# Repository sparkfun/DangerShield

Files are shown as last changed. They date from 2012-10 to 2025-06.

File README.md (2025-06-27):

Danger Shield
=============

[Danger Shield  
*Danger Shield (DEV-10570)*](https://www.sparkfun.com/products/10570)

This is the layout and example code for the Danger Shield product by SparkFun Electronics. It demonstrates each feature of the shield. Move one of the sliders to get a different sound out of the buzzer. Move another slider to change the digit being displayed on the seven segment display. Move the last slider to change the brightness of one of the two status LEDs. Press one of the large buttons to toggle on/off the status LED. Cover the light sensor to 'scare' the unit.

The idea of a Danger Shield was originally created by Zach Hoeken ([http://www.zachhoeken.com/](http://www.zachhoeken.com/))

Repository Contents
-------------------
* **/Firmware** - Example Arduino Sketch
* **/Hardware** - All Eagle design files (.brd, .sch)

Product History
---------------

[DEV-09597](https://www.sparkfun.com/products/9597) - *retired*  
The original version of the Danger Shield which has since been retired.

[DEV-10115](https://www.sparkfun.com/products/10115) - *retired*  
Second version which introduced a knock sensor and a new temperature sensor. Has since been retired.

**[DEV-10570](https://www.sparkfun.com/products/10570) - current version**  
This newest version introduces a capacitive touch sensor. All code in this repository will work best with this version.

License Information
-------------------

The hardware is released under [Creative Commons Share-alike 3.0](http://creativecommons.org/licenses/by-sa/3.0/).  
The code is public domain but you buy me a beer if you use this and we meet someday ([Beerware license](http://en.wikipedia.org/wiki/Beerware)).

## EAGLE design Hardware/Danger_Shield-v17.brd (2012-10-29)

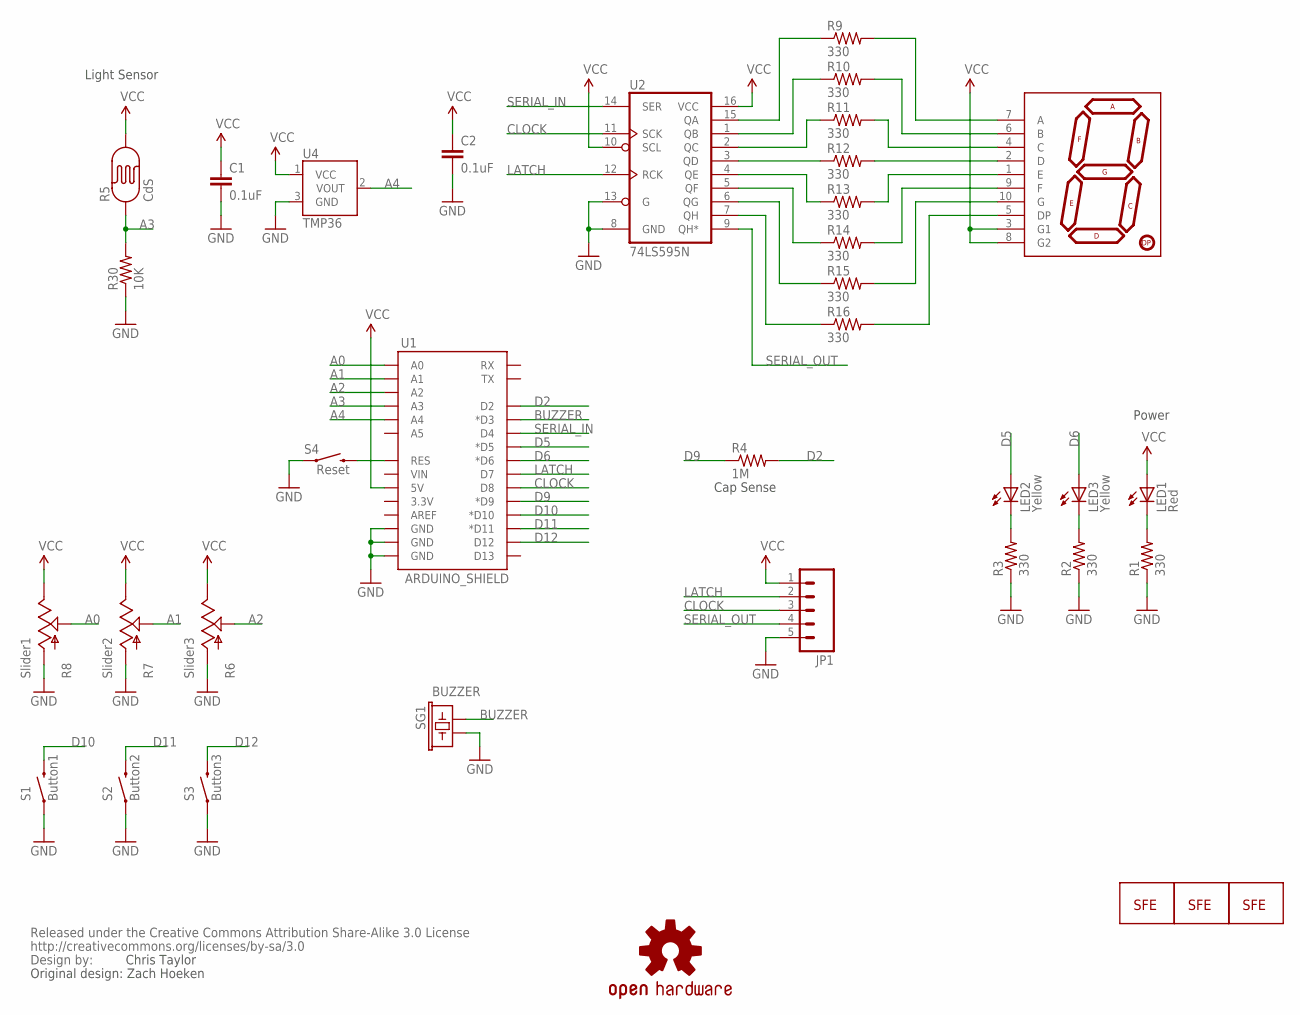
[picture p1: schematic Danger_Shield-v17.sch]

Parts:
C1, C2: 0.1uF; CAP-PTH-SMALL2
JP1: M05PTH; 1X05
JP2, JP3: LOGO-SFENEW; SFE-NEW-WEBLOGO
JP5: LOGO-SFESK; SFE-LOGO-FLAME
LED1: Red; LED5MM
LED2, LED3: Yellow; LED5MM
R1, R2, R3, R9, R10, R11, R12, R13, R14, R15, R16: 330; AXIAL-0.3
R4: 1M; AXIAL-0.3
R5: CdS; PHOTOCELL
R6: Slider3; SLIDER
R7: Slider2; SLIDER
R8: Slider1; SLIDER
R30: 10K; AXIAL-0.3
S1: Button1; TACTILE-PTH-12MM
S2: Button2; TACTILE-PTH-12MM
S3: Button3; TACTILE-PTH-12MM
S4: Reset; TACTILE-PTH
SG1: BUZZER; BUZZER-12MM
U1: ARDUINO_SHIELD; DUEMILANOVE_VIAS
U2: 74LS595N; DIL16
U4: TMP36; TO-92
U6: 7-SEGMENT-DISPLAY-1"-RED; 7-SEGMENT-1"PTH
U$1: CREATIVE_COMMONS
U$2: OSHW-LOGOM; OSHW-LOGO-M

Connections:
A0: R8.2A (S), U1.A0
A1: R7.2A (S), U1.A1
A2: R6.2A (S), U1.A2
A3: R5.1, R30.P$2 (2), U1.A3
A4: U1.A4, U4.2 (VOUT)
BUZZER: SG1.+ (1), U1.D3 (*D3)
CLOCK: JP1.3, U1.D8, U2.11 (SCK)
D2: R4.P$2 (2), U1.D2
D5: LED2.A, U1.D5 (*D5)
D6: LED3.A, U1.D6 (*D6)
D9: R4.P$1 (1), U1.D9 (*D9)
D10: S1.3 (2), U1.D10 (*D10)
D11: S2.3 (2), U1.D11 (*D11)
D12: S3.3 (2), U1.D12
GND: C1.2, C2.2, JP1.5, R1.P$1 (1), R2.P$1 (1), R3.P$1 (1), R6.3 (A), R7.3 (A), R8.3 (A), R30.P$1 (1), S1.1, S2.1, S3.1, S4.1, SG1.- (2), U1.GND@0 (GND), U1.GND@1 (GND), U1.GND@2 (GND), U2.8 (GND), U2.13 (G), U4.3 (GND)
LATCH: JP1.2, U1.D7, U2.12 (RCK)
unnamed: S4.3 (2), U1.RES
unnamed: R9.P$1 (1), U2.15 (QA)
unnamed: LED1.K (C), R1.P$2 (2)
unnamed: R10.P$1 (1), U2.1 (QB)
unnamed: R11.P$1 (1), U2.2 (QC)
unnamed: R12.P$1 (1), U2.3 (QD)
unnamed: R13.P$1 (1), U2.4 (QE)
unnamed: R14.P$1 (1), U2.5 (QF)
unnamed: R15.P$1 (1), U2.6 (QG)
unnamed: R16.P$1 (1), U2.7 (QH)
unnamed: R9.P$2 (2), U6.7 (A)
unnamed: R10.P$2 (2), U6.6 (B)
unnamed: R11.P$2 (2), U6.4 (C)
unnamed: R12.P$2 (2), U6.2 (D)
unnamed: R13.P$2 (2), U6.1 (E)
unnamed: R14.P$2 (2), U6.9 (F)
unnamed: R15.P$2 (2), U6.10 (G)
unnamed: R16.P$2 (2), U6.5 (DP)
unnamed: LED3.K (C), R2.P$2 (2)
unnamed: LED2.K (C), R3.P$2 (2)
SERIAL_IN: U1.D4, U2.14 (SER)
SERIAL_OUT: JP1.4, U2.9 (QH*)
VCC: C1.1, C2.1, JP1.1, LED1.A, R5.2, R6.1 (E), R7.1 (E), R8.1 (E), U1.5V, U2.10 (SCL), U2.16 (VCC), U4.1 (VCC), U6.3 (G1), U6.8 (G2)

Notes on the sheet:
Power
Light Sensor
Cap Sense
Chris Taylor
Original design: Zach Hoeken

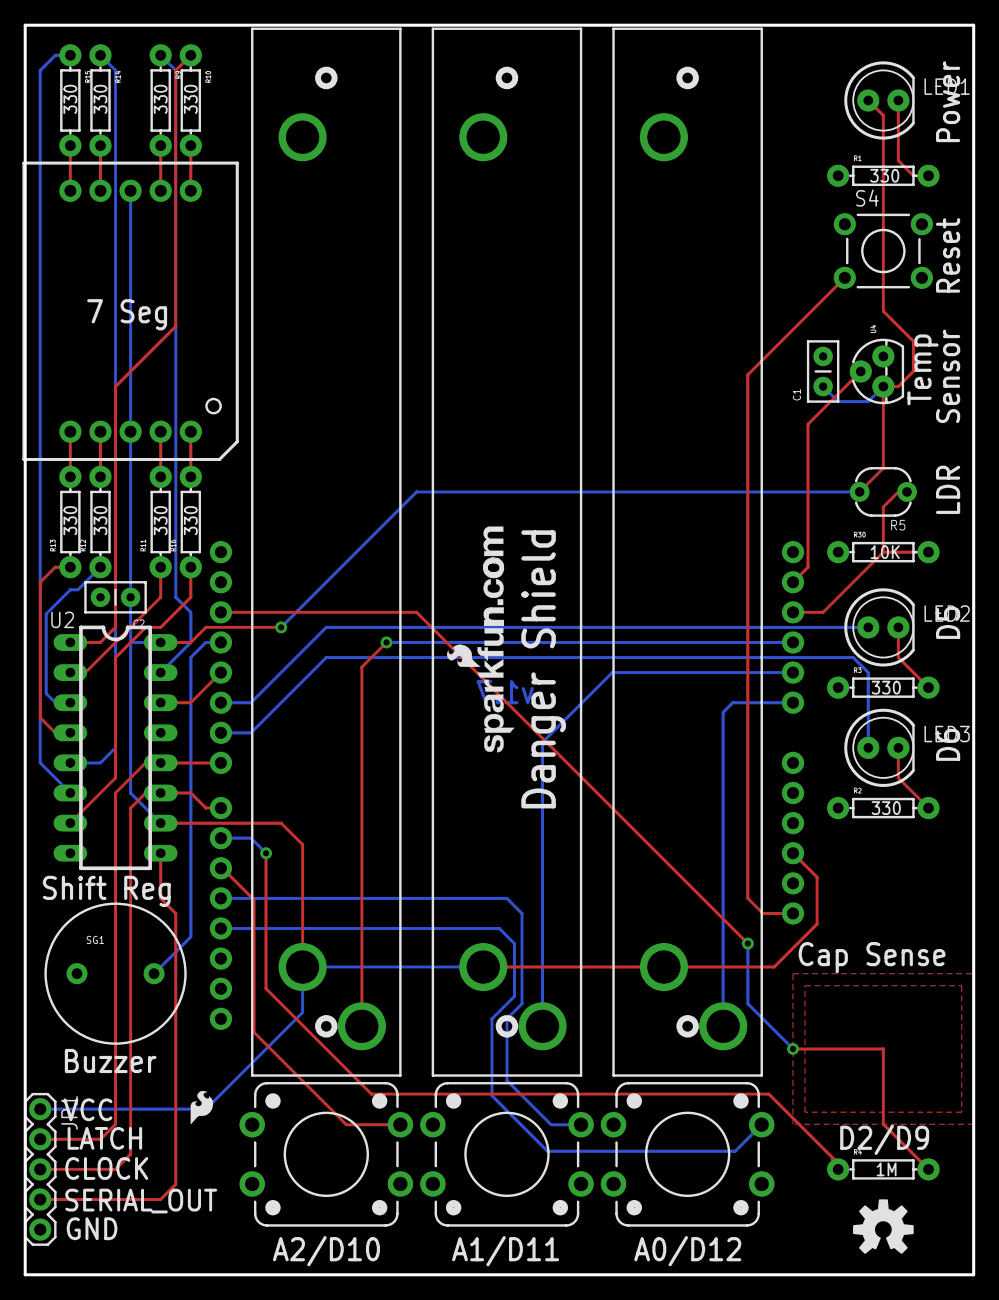
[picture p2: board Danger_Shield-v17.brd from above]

Board: 2 copper layers, 80.0 x 105.4 mm, 37 parts (1 on the bottom side), 39 nets.

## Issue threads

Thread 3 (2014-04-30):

map() scales the slider values from 0 to 1020?

bhuang10000, 2014-04-30:
In the sample code, the slider values are scaled from a range of 0 to 1020 not 0 to 1023? Is there a reason for this?

Marsfan, 2015-01-14:
I just forked and fixed this.
Pull request submitted.

ToniCorinne, 2016-03-09:
Fixed with merging pull request #4

Closed 2016-03-09.

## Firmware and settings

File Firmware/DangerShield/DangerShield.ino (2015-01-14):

/*
 Danger Shield Example Sketch
 Written by Chris Taylor 3-3-2010
 Tweaked by Nathan Seidle 10-22-2012
 Spark Fun Electronics
 
 This code is public domain but you buy me a beer if you use this and we meet someday (Beerware license).
 The project is OSHW and the schematic is released under Creative Commons Share Alike w/ Attribution v3.0
 
 This is the example code, created in Arduino v1.0.1 for the Danger Shield product by SparkFun Electronics. 
 It demonstrates each feature of the shield. Move one of the sliders to get a different sound out of the buzzer. 
 Move another slider to change the digit being displayed on the seven segment display. Move the last slider to 
 change the brightness of one of the two status LEDs. Press one of the large buttons to toggle on/off the status LED. 
 Cover the light sensor to 'scare' the unit. Open a terminal window at 9600bps if you'd like to see the
 values change over the serial connection.
 
 This code works best with product SKU 10115: https://www.sparkfun.com/products/10115
 
 Knock sensor, new temp sensor: https://www.sparkfun.com/products/10115
 Cap touch sensor: https://www.sparkfun.com/products/10570
 
 The idea of a Danger Shield was originally created by Zach Hoeken (http://www.zachhoeken.com/) released CC-SA.
 
 */

// Shift register bit values to display 0-9 on the seven-segment display
const byte ledCharSet[10] = {
  B00111111, 
  B00000110, 
  B01011011, 
  B01001111, 
  B01100110, 
  B01101101, 
  B01111101, 
  B00000111, 
  B01111111, 
  B01101111
};

// Pin definitions

//-=-=-=-=-=-=-=-=-=-=-=-=-=-=-=-=-=-=-=-=
//These pin definitions are for v1.6 of the board
/*
#define SLIDER1  A0
 #define SLIDER2  A1
 #define SLIDER3  A2
 #define LIGHT    A3
 #define TEMP     A4
 #define KNOCK    A5
 
 #define DATA     4
 #define LED1     5
 #define LED2     6
 #define LATCH    7
 #define CLOCK    8
 #define BUZZER   9
 #define BUTTON1  10
 #define BUTTON2  11
 #define BUTTON3  12
 //-=-=-=-=-=-=-=-=-=-=-=-=-=-=-=-=-=-=-=-=
 */

//-=-=-=-=-=-=-=-=-=-=-=-=-=-=-=-=-=-=-=-=
//These pin definitions are for v1.7 of the board
#define SLIDER1  A2 //Matches button 1
#define SLIDER2  A1 
#define SLIDER3  A0 //Matches button 3
#define LIGHT    A3
#define TEMP     A4

#define BUZZER   3
#define DATA     4
#define LED1     5
#define LED2     6
#define LATCH    7
#define CLOCK    8
#define BUTTON1  10
#define BUTTON2  11
#define BUTTON3  12
//v1.7 uses CapSense
//This relies on the Capactive Sensor library here: http://playground.arduino.cc/Main/CapacitiveSensor
#include <CapacitiveSensor.h>

CapacitiveSensor capPadOn92 = CapacitiveSensor(9, 2);   //Use digital pins 2 and 9,
//-=-=-=-=-=-=-=-=-=-=-=-=-=-=-=-=-=-=-=-=

int avgLightLevel;

void setup()
{
  Serial.begin(9600);

  //Initialize inputs and outputs
  pinMode(SLIDER1, INPUT);
  pinMode(SLIDER2, INPUT);
  pinMode(SLIDER3, INPUT);
  pinMode(LIGHT, INPUT);
  pinMode(TEMP, INPUT);

  //Enable internal pullups
  pinMode(BUTTON1, INPUT_PULLUP);
  pinMode(BUTTON2, INPUT_PULLUP);
  pinMode(BUTTON3, INPUT_PULLUP);

  pinMode(BUZZER, OUTPUT);
  pinMode(LED1, OUTPUT);
  pinMode(LED2, OUTPUT);

  pinMode(LATCH, OUTPUT);
  pinMode(CLOCK, OUTPUT);
  pinMode(DATA, OUTPUT);

  //Initialize the capsense
  capPadOn92.set_CS_AutocaL_Millis(0xFFFFFFFF); // Turn off autocalibrate on channel 1 - From Capacitive Sensor example sketch

  Serial.println("Danger Shield Component Test");  

  //Take 16 readings from the light sensor and average them together
  avgLightLevel = 0;
  for(int x = 0 ; x < 16 ; x++)
    avgLightLevel += analogRead(LIGHT);
  avgLightLevel /= 16;
  Serial.print("Avg: ");
  Serial.println(avgLightLevel);

}

void loop()
{
  //Read inputs
  int val1 = analogRead(SLIDER1);
  int val2 = analogRead(SLIDER2);
  int val3 = analogRead(SLIDER3);
  int lightLevel = analogRead(LIGHT);
  long temperature = analogRead(TEMP);

  //Read the cap sense pad
  long capLevel = capPadOn92.capacitiveSensor(30);
  
  //Do conversion of temp from analog value to digital
  temperature *= 5000; //5V is the same as 1023 from the ADC (12-bit) - example, the ADC returns 153 * 5000 = 765,000
  temperature /= 1023; //It's now in mV - 765,000 / 1023 = 747
  //The TMP36 reports 500mV at 0C so let's subtract off the 500mV offset
  temperature -= 500; //747 - 500 = 247
  //Temp is now in C where 247 = 24.7

  //Display values
  //sprintf is a great way to combine a bunch of variables and strings together into one print statement
  char tempString[200];
  sprintf(tempString, "Sliders: %04d %04d %04d Light: %04d Capsense: %04d", val1, val2, val3, lightLevel, capLevel);
  Serial.print(tempString); 
  sprintf(tempString, " Temp: %03d.%01dC", (int)temperature/10, (int)temperature%10);
  Serial.print(tempString); 

  //If user is hitting button 1, turn on LED 1
  if(digitalRead(BUTTON1) == LOW)
  {
    Serial.print(" Button 1!");
    digitalWrite(LED1, HIGH);
  }
  else
    digitalWrite(LED1, LOW);

  Serial.println();

  //Set the brightness on LED #2 (D6) based on slider 1
  int ledLevel = map(val1, 0, 1023, 0, 255); //Map the slider level to a value we can set on the LED
  analogWrite(LED2, ledLevel); //Set LED brightness

  //Set 7 segment display based on the 2nd slider
  int numToDisplay = map(val2, 0, 1023, 0, 9); //Map the slider value to a displayable value
  digitalWrite(LATCH, LOW);
  shiftOut(DATA, CLOCK, MSBFIRST, ~(ledCharSet[numToDisplay]));
  digitalWrite(LATCH, HIGH);

  //Set the sound based on the 3rd slider
  long buzSound = map(val3, 0, 1023, 1000, 10000); //Map the slider value to an audible frequency
  if(buzSound > 1100)
    tone(BUZZER, buzSound); //Set sound value
  else
    noTone(BUZZER);

  //If light sensor is less than 3/4 of the average (covered up) then freak out
  while(lightLevel < (avgLightLevel * 3 / 4))
  {
    //Blink the status LEDs back and forth
    if(digitalRead(LED1) == LOW)
    {
      digitalWrite(LED1, HIGH);
      digitalWrite(LED2, LOW);
    }
    else {
      digitalWrite(LED1, LOW);
      digitalWrite(LED2, HIGH);
    }

    //Display an increasing number on the 7-segment display
    digitalWrite(LATCH, LOW);
    shiftOut(DATA, CLOCK, MSBFIRST, ~(ledCharSet[numToDisplay]));
    digitalWrite(LATCH, HIGH);
    numToDisplay++; //Goto next number
    if(numToDisplay > 9) numToDisplay = 0; //Loop number

    //Play a horrendously annoying sound
    //Frequency increases with each loop
    tone(BUZZER, buzSound);
    buzSound += 100;
    if(buzSound > 3000) buzSound = 1000;

    delay(25);

    lightLevel = analogRead(LIGHT); //We need to take another reading to be able to exit the while loop
  }
}

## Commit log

2012-10-22 Original commit, but new version of example code
    New example code does not require terminal or button pressing to cycle
    through features.
    [Danger_Shield-v14.brd, Danger_Shield-v14.sch, Danger_Shield-v16.brd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]
2012-10-22 v1.7 changes temp sensor to TMP36. Add 2 caps.
    Removed 10k on temp sensor. Changed to TMP36. Added 2 x 0.1uF caps for
    decoupling on shift register and temp sensor.
    [Danger_Shield-v17.brd, Danger_Shield-v17.sch]
2012-10-22 Cosmetic updates to schematic.
2012-10-22 Added CC license to schematic and PCB.
    [Danger_Shield-v17.brd, Danger_Shield-v17.sch]
2012-10-22 Added version # 1.7 to PCB.
    [Danger_Shield-v17.brd]
2012-10-28 Update to gitignore. Added OSHW logo. Fixed overlapping resistors.
    Cleaned up the example code slightly as well. Trying to fit into
    SparkFun coding standards.
    [Danger_Shield-v17.brd, Danger_Shield-v17.sch]
2012-10-29 Adding dimensional and BOM.
    [Danger_Shield-v17.brd, Danger_Shield-v17.sch]
2013-01-10 Added support for v1.7 PCB.
    Used sprintfs to print the the readings in a pretty way. Added
    CapacitiveSense based on latest Arduino library (it's no longer
    capsense, instead it's CapacitiveSense).
    [DangerShield.ino]
2013-09-03 Fixing repo structure, and updating README
    [Danger_Shield-v14.brd, Danger_Shield-v14.sch, Danger_Shield-v16.brd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]
2015-01-14 Fixed map() functions
    functions now map fro 0 to 1023 instead of 0 to 1020
    [DangerShield.ino]

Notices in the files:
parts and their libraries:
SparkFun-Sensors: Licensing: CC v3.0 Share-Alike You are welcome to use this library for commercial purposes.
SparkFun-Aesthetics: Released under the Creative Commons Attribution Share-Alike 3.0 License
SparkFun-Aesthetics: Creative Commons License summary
